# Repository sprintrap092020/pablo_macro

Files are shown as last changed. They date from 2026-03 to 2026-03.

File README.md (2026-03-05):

Hi everyone. I want to introduce you my first ever project. This is macropad(minikeyboard) with mechanical cherry mx switches.

its based on 1x seeed xiao rp2040 12x cherry mx switches 12x 1n4148 diodes(dip) 1x ec11 encoder and 12x sk6812mini-e adress leds and one 330 ohm resistor(0.25w) 

also i made case for that stuff in fusion so you can use itwithout any problems
all of them are called pablo_macro_case

pablo_macro_case is main case 

pablo_macro_case_lid is lid for that case
in summary case is 117x77x19mm (raw case without switches and keycaps)

to assemble this whole thing you need to obtain pcb case case lid and all components from above
also you will need soldering iron and flux to make stable connections beetwen components and pcb



case_all_render_2026-Mar-05_09-32-31PM-000_CustomizedView13269693666
case_all_render_2026-Mar-05_09-36-58PM-000_CustomizedView4011999680

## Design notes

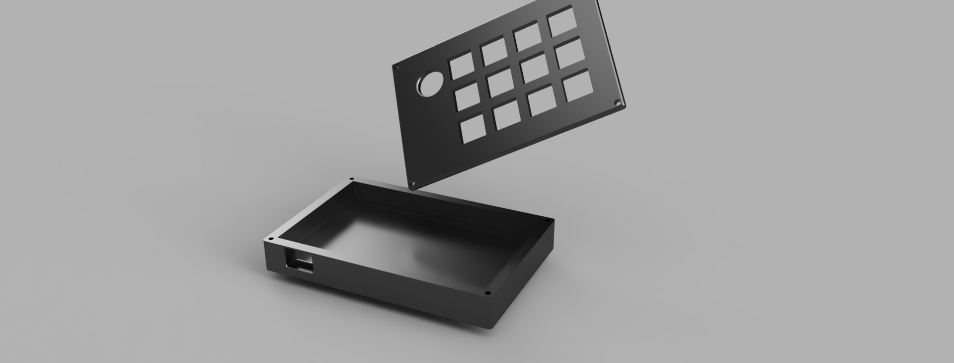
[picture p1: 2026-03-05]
case_all_render_2026-Mar-05_09-36-58PM-000_CustomizedView4011999680.png

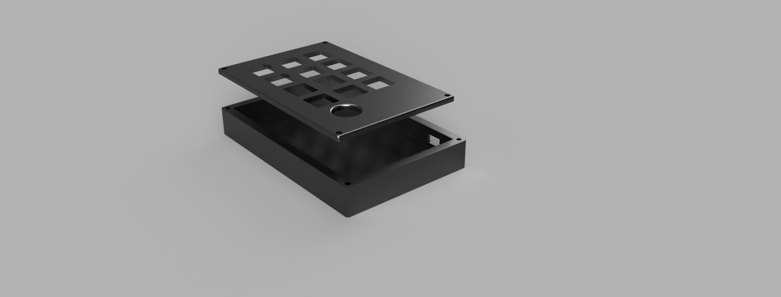
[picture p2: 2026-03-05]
case_all_render_2026-Mar-05_09-32-31PM-000_CustomizedView13269693666.png

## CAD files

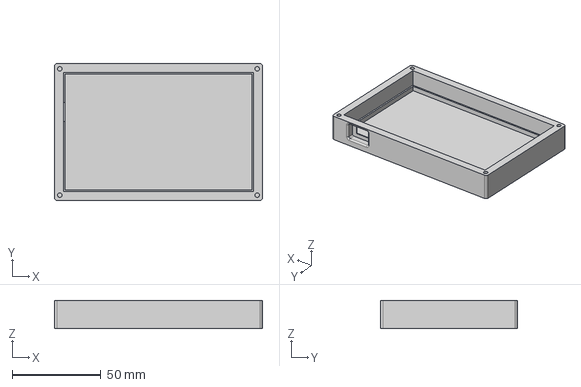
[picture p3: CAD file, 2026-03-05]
pablo_macro_case.step
117.0 x 77.0 x 16.0 mm

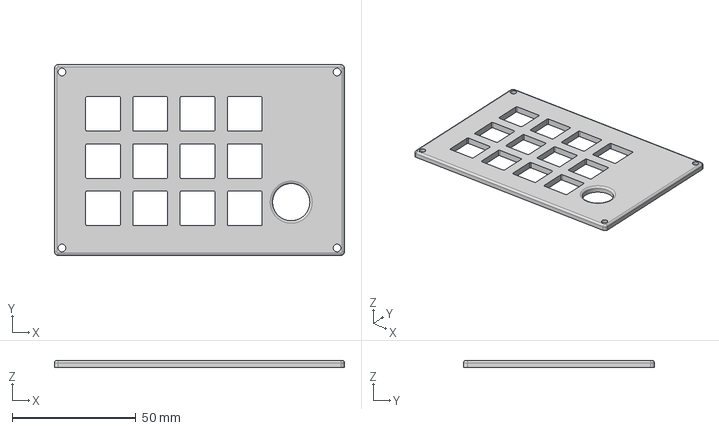
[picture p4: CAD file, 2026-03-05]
pablo_macro_case_lid.step
117.0 x 77.0 x 3.00 mm

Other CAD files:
pablo_macro_case.f3d
pablo_macro_case.stl
pablo_macro_case_lid.f3d
pablo_macro_case_lid.stl

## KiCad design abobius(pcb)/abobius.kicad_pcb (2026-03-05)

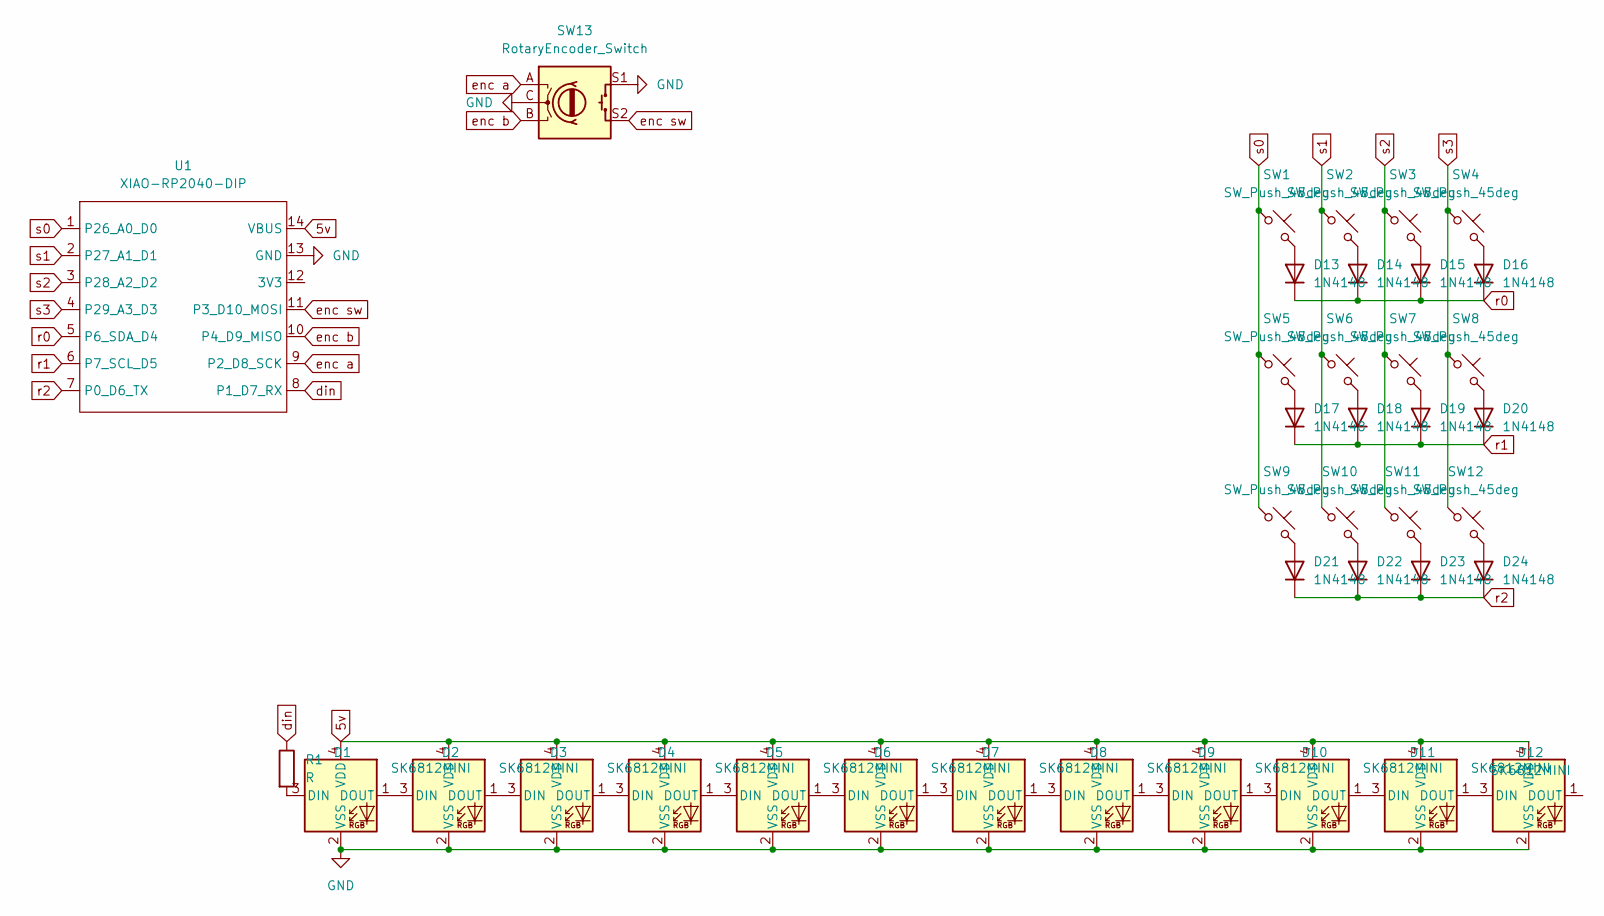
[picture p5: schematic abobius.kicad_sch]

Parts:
D1, D2, D3, D4, D5, D6, D7, D8, D9, D10, D11, D12: SK6812MINI; LED_SK6812MINI_PLCC4_3.5x3.5mm_P1.75mm
D13, D14, D15, D16, D17, D18, D19, D20, D21, D22, D23, D24: 1N4148; D_DO-35_SOD27_P7.62mm_Horizontal
R1: R; R_Axial_DIN0207_L6.3mm_D2.5mm_P7.62mm_Horizontal
SW1, SW2, SW3, SW4, SW5, SW6, SW7, SW8, SW9, SW10, SW11, SW12: SW_Push_45deg; SW_Cherry_MX_1.00u_PCB
SW13: RotaryEncoder_Switch; RotaryEncoder_Alps_EC11E-Switch_Vertical_H20mm
U1: XIAO-RP2040-DIP; Seeed_XIAO_RP2040

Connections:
5v: D1.4 (VDD), D2.4 (VDD), D3.4 (VDD), D4.4 (VDD), D5.4 (VDD), D6.4 (VDD), D7.4 (VDD), D8.4 (VDD), D9.4 (VDD), D10.4 (VDD), D11.4 (VDD), D12.4 (VDD), U1.14 (VBUS)
GND: D1.2 (VSS), D2.2 (VSS), D3.2 (VSS), D4.2 (VSS), D5.2 (VSS), D6.2 (VSS), D7.2 (VSS), D8.2 (VSS), D9.2 (VSS), D10.2 (VSS), D11.2 (VSS), D12.2 (VSS), SW13.C, SW13.S1, U1.13 (GND)
unnamed: D1.3 (DIN), R1.2
unnamed: D1.1 (DOUT), D2.3 (DIN)
unnamed: D2.1 (DOUT), D3.3 (DIN)
unnamed: D3.1 (DOUT), D4.3 (DIN)
unnamed: D4.1 (DOUT), D5.3 (DIN)
unnamed: D5.1 (DOUT), D6.3 (DIN)
unnamed: D6.1 (DOUT), D7.3 (DIN)
unnamed: D7.1 (DOUT), D8.3 (DIN)
unnamed: D8.1 (DOUT), D9.3 (DIN)
unnamed: D9.1 (DOUT), D10.3 (DIN)
unnamed: D10.1 (DOUT), D11.3 (DIN)
unnamed: D11.1 (DOUT), D12.3 (DIN)
unnamed: D13.2 (A), SW1.2
unnamed: D14.2 (A), SW2.2
unnamed: D15.2 (A), SW3.2
unnamed: D16.2 (A), SW4.2
unnamed: D17.2 (A), SW5.2
unnamed: D18.2 (A), SW6.2
unnamed: D19.2 (A), SW7.2
unnamed: D20.2 (A), SW8.2
unnamed: D21.2 (A), SW9.2
unnamed: D22.2 (A), SW10.2
unnamed: D23.2 (A), SW11.2
unnamed: D24.2 (A), SW12.2
din: R1.1, U1.8 (P1_D7_RX)
enc a: SW13.A, U1.9 (P2_D8_SCK)
enc b: SW13.B, U1.10 (P4_D9_MISO)
enc sw: SW13.S2, U1.11 (P3_D10_MOSI)
r0: D13.1 (K), D14.1 (K), D15.1 (K), D16.1 (K), U1.5 (P6_SDA_D4)
r1: D17.1 (K), D18.1 (K), D19.1 (K), D20.1 (K), U1.6 (P7_SCL_D5)
r2: D21.1 (K), D22.1 (K), D23.1 (K), D24.1 (K), U1.7 (P0_D6_TX)
s0: SW1.1, SW5.1, SW9.1, U1.1 (P26_A0_D0)
s1: SW2.1, SW6.1, SW10.1, U1.2 (P27_A1_D1)
s2: SW3.1, SW7.1, SW11.1, U1.3 (P28_A2_D2)
s3: SW4.1, SW8.1, SW12.1, U1.4 (P29_A3_D3)

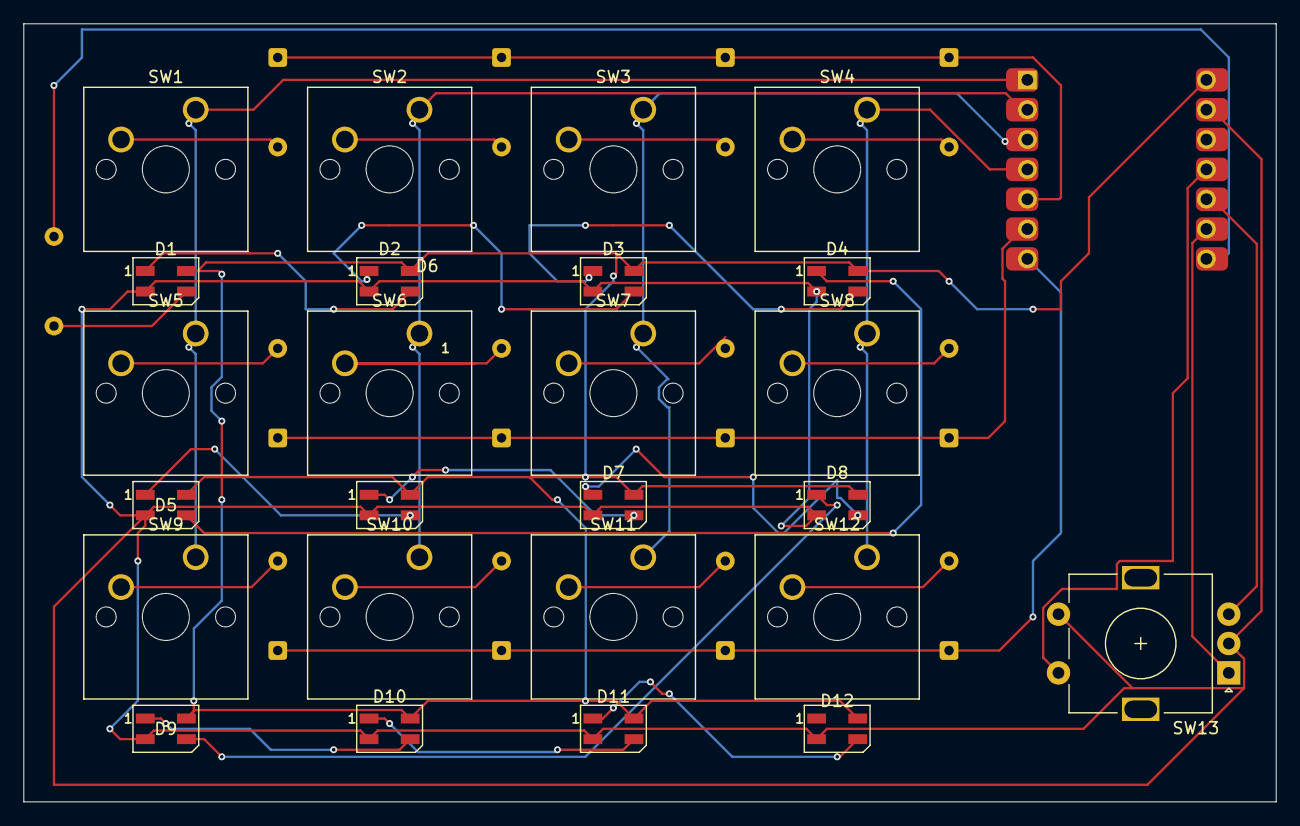
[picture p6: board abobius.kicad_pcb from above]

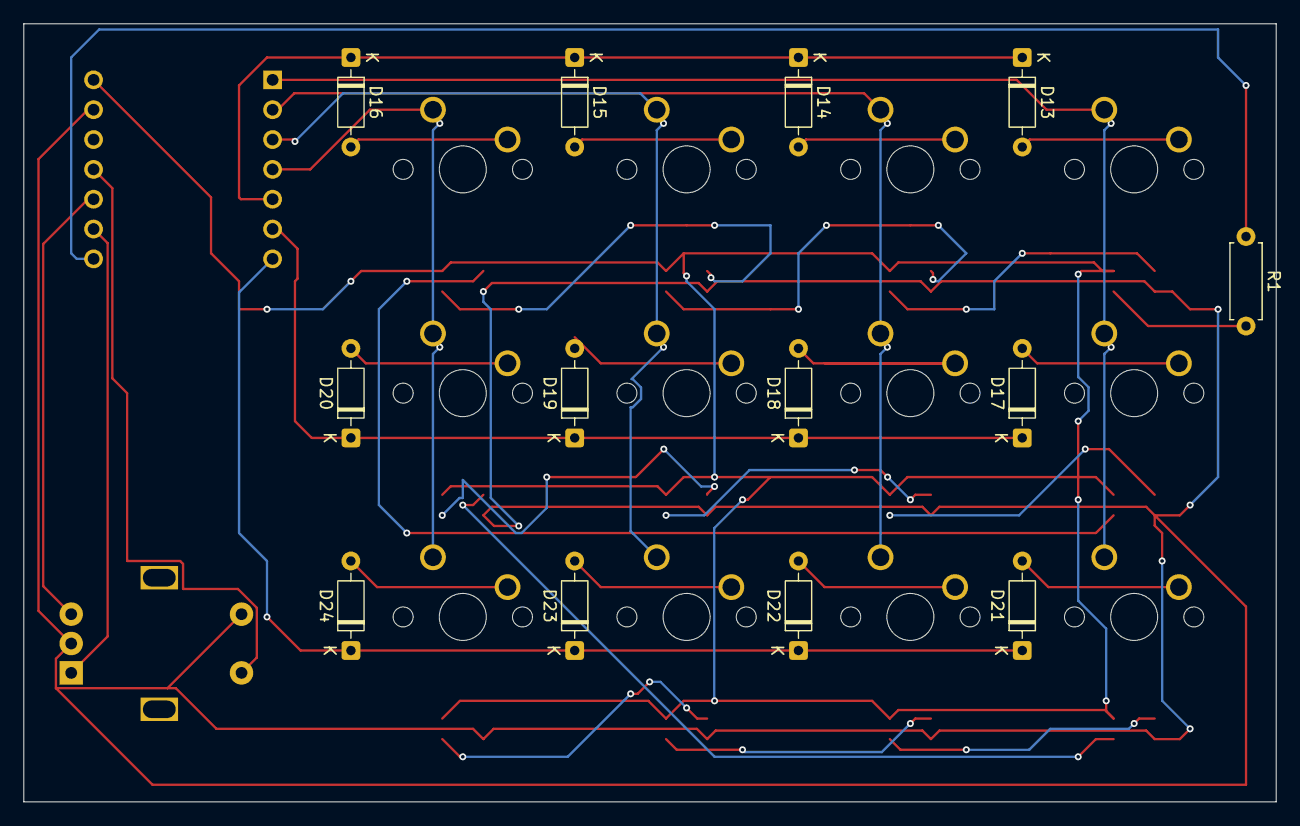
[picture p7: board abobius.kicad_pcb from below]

Board: 2 copper layers, 106.6 x 66.2 mm, 39 parts (13 on the bottom side), 37 nets.

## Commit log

2026-03-05 Add project introduction for macropad
    Introduced project details for macropad with components and case information.
2026-03-05 Update README with case dimensions and assembly info
    Added summary dimensions and assembly requirements.
